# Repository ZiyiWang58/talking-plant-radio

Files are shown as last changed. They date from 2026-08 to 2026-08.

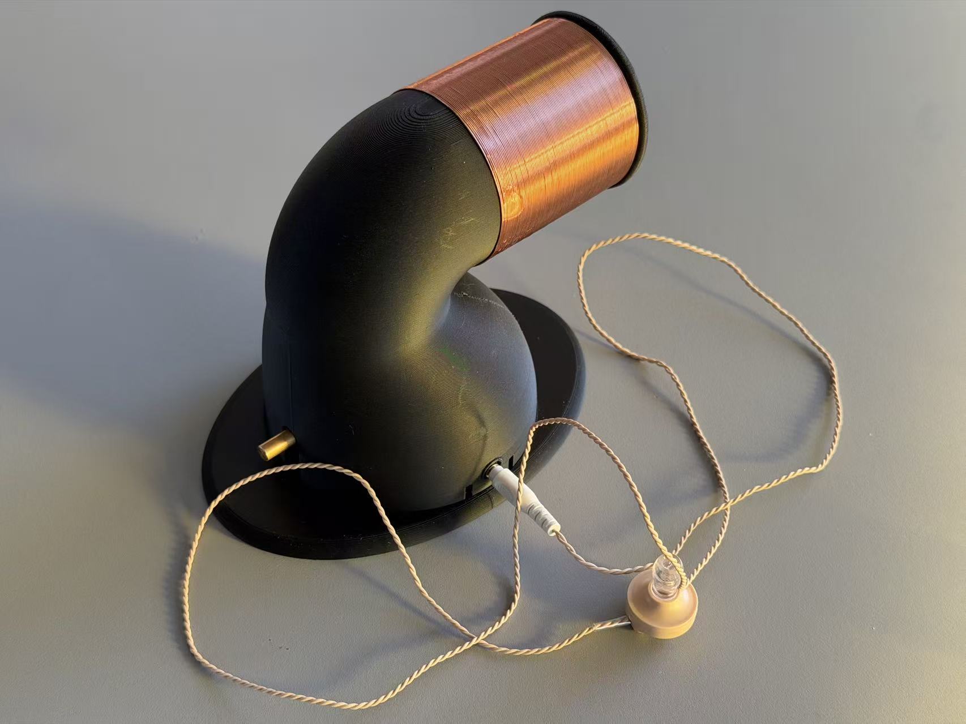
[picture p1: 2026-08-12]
hardware/images/05.jpg

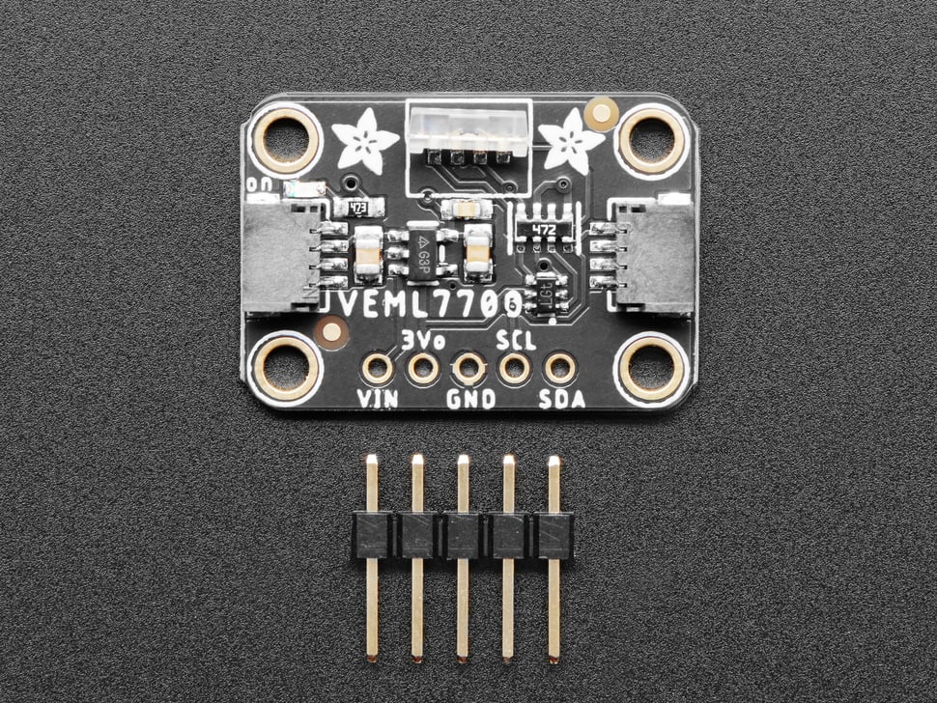
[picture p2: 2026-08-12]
hardware/images/light.jpg

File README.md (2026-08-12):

# TuneIn: Talking Plants over the AM Waveband

TuneIn is a single-prayer-plant installation that senses soil moisture,
temperature, humidity, illuminance and spectral light composition. A Raspberry
Pi classifies the readings, generates a short first-person message with Azure
OpenAI or preset fallback sentences, synthesises speech with Azure Speech,
processes it for AM intelligibility with FFmpeg and plays it into the physical
AM transmitter. A phone-friendly Flask page shows the latest reading and spoken
message.

This repository is based on the final Raspberry Pi program
`plant_pi_controller_local_playback.py`.

## Repository contents

| Path | Purpose |
| --- | --- |
| `plant_pi_controller_local_playback.py` | Final sensing, interpretation, text, TTS, audio and logging loop |
| `display_server.py` | Self-contained status webpage and JSON endpoint |
| `start_demo.sh` | Starts the controller with PipeWire playback |
| `start_main_service.sh` | Waits for the user audio session, then starts the controller |
| `start_display.sh` | Starts the Flask display |
| `tests/` | Four-sensor and AS7341-only hardware checks |
| `requirements.txt` | Direct Python dependencies used by the project |
| `requirements-lock.txt` | Complete package versions exported from the deployed `.venv` |
| `.env.example` | Safe configuration template without credentials |
| `systemd/` | Optional user-service templates for automatic startup |
| `docs/` | Calibration, timing and source-verification notes |
| `hardware/` | Required physical-documentation checklist |

## Final deployed settings represented here

- One prayer plant: *Maranta leuconeura*.
- Azure OpenAI enabled, with a maximum of 24 words and a 12-second timeout.
- Preset first-person sentences used automatically if the LLM is disabled or
  unavailable, times out or returns unusable text.
- Azure voice `en-US-JennyNeural`.
- 16 kHz, 16-bit, mono WAV synthesis; SSML rate `-10%`, pitch `0%`, with a
  250 ms break inserted between sentences.
- FFmpeg filtering: 300 Hz high-pass, 3.2 kHz low-pass, compression and loudness
  normalisation.
- Local PipeWire playback enabled; MQTT disabled.
- Five-second wait after each complete broadcast cycle.

## Raspberry Pi setup

The deployed environment used Python 3.13. A Raspberry Pi OS installation with
I²C enabled, working network access, a PipeWire audio sink and the four connected
sensors is required.

1. Install system packages:

   ```bash
   sudo apt update
   sudo apt install -y git python3-venv python3-pip ffmpeg pipewire-bin
   ```

2. Enable I²C with `sudo raspi-config`, then reboot if prompted.

3. Clone the repository to `~/TuneIn` and enter it:

   ```bash
   git clone https://github.com/ZiyiWang58/talking-plant-radio.git ~/TuneIn
   cd ~/TuneIn
   ```

4. Create the virtual environment and install the locked packages:

   ```bash
   python3 -m venv .venv
   ./.venv/bin/python -m pip install --upgrade pip
   ./.venv/bin/python -m pip install -r requirements-lock.txt
   ```

   Use `requirements.txt` instead when only the project's direct dependencies
   should be pinned and pip may resolve their subdependencies.

5. Create the private configuration:

   ```bash
   cp .env.example .env
   nano .env
   ```

   Enter the Azure Speech key and region. If Azure OpenAI is enabled, also enter
   its endpoint, key and deployment name. Never commit `.env`.

## Test the sensors

Run the combined soil, lux, temperature and humidity test:

```bash
./.venv/bin/python tests/sensor_test.py
```

Run the AS7341 spectral test separately:

```bash
./.venv/bin/python tests/test_as7341.py
```

Both programs continue until `Ctrl+C` is pressed.

## Select and test the audio output

List PipeWire devices:

```bash
wpctl status
```

If the Pi analogue output is already the default, start the controller with:

```bash
./start_demo.sh
```

Otherwise provide the sink ID shown by `wpctl status`:

```bash
PIPEWIRE_SINK=57 PIPEWIRE_VOLUME=60% ./start_demo.sh
```

The number `57` was used by the final exhibit but is not portable; PipeWire may
assign a different ID after reboot or on another Raspberry Pi.

## Start the phone display

In a second terminal:

```bash
./start_display.sh
```

Open `http://PI_IP_ADDRESS:5000` on a device that can reach the Raspberry Pi.
The page requests `/api/status` every two seconds and displays the newest row
from `logs/broadcast_log.csv`. The controller creates this file automatically.
The Flask server binds to all interfaces, so expose it only on a trusted local
network or private overlay network, not directly to the public internet.

## Optional automatic startup

The included user-service templates assume the repository is `~/TuneIn`:

```bash
mkdir -p ~/.config/systemd/user
cp systemd/tunein-controller.service ~/.config/systemd/user/
cp systemd/tunein-display.service ~/.config/systemd/user/
systemctl --user daemon-reload
systemctl --user enable --now tunein-controller.service
systemctl --user enable --now tunein-display.service
```

To keep user services running without an interactive login, an administrator
can enable lingering for the Pi account:

```bash
sudo loginctl enable-linger "$USER"
```

If the analogue sink is not the default, edit the controller service and set
`PIPEWIRE_SINK` to the correct ID before enabling it.

## Runtime files

The controller generates these files, all excluded by `.gitignore`:

- `latest_plant_voice_raw.wav` — Azure Speech output;
- `latest_plant_voice.wav` — filtered AM-oriented output;
- `logs/broadcast_log.csv` — readings, states, message source and playback status.

The web display requires no `templates/` or `static/` directory because its
HTML, CSS and JavaScript are embedded in `display_server.py`.

## Reproducibility boundary

The software side is represented by the final controller, display, dependency
versions, safe configuration template, tests and startup files. Full physical
reproduction still requires the exact AM transmitter, coupling coil, crystal
radio, wiring, bill of materials and enclosure documentation listed in
`hardware/README.md`. Add only materials verified against the final exhibit.

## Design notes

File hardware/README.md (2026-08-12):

# Hardware Documentation

This page records the main hardware used in the final TuneIn prototype. The
software expects one Raspberry Pi connected to four I2C environmental sensors,
with processed speech audio sent from the Raspberry Pi into a short-range AM
transmitter and received through a crystal-radio setup.

## Bill of Materials

| Component | Model / Specification | Quantity |
| --- | --- | ---: |
| Raspberry Pi | Raspberry Pi 4B | 1 |
| Soil moisture sensor | Adafruit STEMMA Soil Sensor, I2C capacitive moisture sensor | 1 |
| Temperature and humidity sensor | Adafruit SHT31-D Temperature & Humidity Sensor | 1 |
| Ambient light sensor | Adafruit VEML7700 Ambient Light Sensor, I2C lux sensor | 1 |
| Spectral sensor | AS7341 visible light spectral sensor | 1 |
| I2C wiring / jumper wires | I2C connection between sensors and Raspberry Pi | As required |
| 3.5 mm audio output | Raspberry Pi audio output to AM transmitter input | 1 |
| 1 MHz crystal oscillator | Fixed-frequency oscillator module | 1 |
| LM386 audio amplifier | Low-voltage audio power amplifier IC | 1 |
| Potentiometer | 10 kΩ potentiometer | 1 |
| Capacitor | 220 pF ceramic capacitor | 1 |
| Capacitor | 47 nF ceramic capacitor | 1 |
| Capacitor | 100 nF ceramic capacitor | 3 |
| Capacitor | 1 µF electrolytic capacitor pack | 1 |
| Capacitor | 10 µF electrolytic capacitor pack | 1 |
| Capacitor | 100 µF electrolytic capacitor pack | 1 |
| Capacitor | 220 µF electrolytic capacitor pack | 1 |
| Capacitor | 60 pF trimmer capacitor | 1 |
| Resistor | 10 Ω | 1 |
| Resistor | 220 Ω | 1 |
| Resistor | 4.7 kΩ | 1 |
| Resistor | 100 kΩ | 1 |
| Audio transformer | LT700 miniature audio transformer | 1 |
| RF transistor | 2N2222 NPN transistor | 1 |
| Transmitting coil | Hand-wound coil / loop tuned around the AM carrier frequency | 1 |
| Receiver coil | Tuned coil forming an LC circuit around 1 MHz | 1 |
| Tuning capacitor | Variable or fixed capacitor matched with receiver coil | 1 |
| Detector diode | Germanium diode | 1 |
| High-impedance earphone | High-impedance listening device or amplified audio input | 1 |
| Plant pot enclosure | Single prayer plant pot structure | 1 |
| Power supply | Raspberry Pi power adapter and circuit power supply | 1 |

## Sensor Addresses

| Sensor | Purpose | Address used by the software |
| --- | --- | ---: |
| Adafruit STEMMA soil sensor / Seesaw | Relative soil moisture | `0x36` |
| VEML7700 | Illuminance | `0x10` |
| SHT31-D | Temperature and humidity | `0x44` |
| AS7341 | Visible spectral composition | `0x39` |

All four sensors share the Raspberry Pi I2C bus using the standard SDA and SCL
pins. The final AM reception quality depended on coil placement, orientation,
tuning and nearby electronic interference, so the hand-wound coil and tuning
values should be verified against the final physical exhibit rather than
inferred from the software alone.

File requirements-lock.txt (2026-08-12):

Adafruit-Blinka==9.1.0
Adafruit-Blinka-Raspberry-Pi5-Neopixel==1.0.0rc2
adafruit-circuitpython-as7341==1.2.27
adafruit-circuitpython-busdevice==5.2.17
adafruit-circuitpython-connectionmanager==3.1.8
adafruit-circuitpython-pixelbuf==2.0.12
adafruit-circuitpython-register==1.11.3
adafruit-circuitpython-requests==4.1.17
adafruit-circuitpython-seesaw==1.18.2
adafruit-circuitpython-sht31d==2.3.31
adafruit-circuitpython-typing==1.12.3
adafruit-circuitpython-veml7700==2.2.2
Adafruit-PlatformDetect==3.88.0
Adafruit-PureIO==1.1.11
annotated-types==0.7.0
anyio==4.14.0
azure-cognitiveservices-speech==1.50.0
azure-core==1.41.0
binho-host-adapter==0.1.6
blinker==1.9.0
certifi==2026.5.20
charset-normalizer==3.4.7
click==8.4.2
distro==1.9.0
Flask==3.1.3
h11==0.16.0
httpcore==1.0.9
httpx==0.28.1
idna==3.16
itsdangerous==2.2.0
Jinja2==3.1.6
jiter==0.15.0
MarkupSafe==3.0.3
openai==2.43.0
paho-mqtt==2.1.0
pydantic==2.13.4
pydantic_core==2.46.4
pyftdi==0.57.1
pyserial==3.5
python-dotenv==1.2.2
pyusb==1.3.1
requests==2.34.2
RPi.GPIO==0.7.1
rpi_ws281x==5.0.0
sniffio==1.3.1
sysv_ipc==1.2.0
tqdm==4.68.3
typing-inspection==0.4.2
typing_extensions==4.15.0
urllib3==2.7.0
Werkzeug==3.1.8

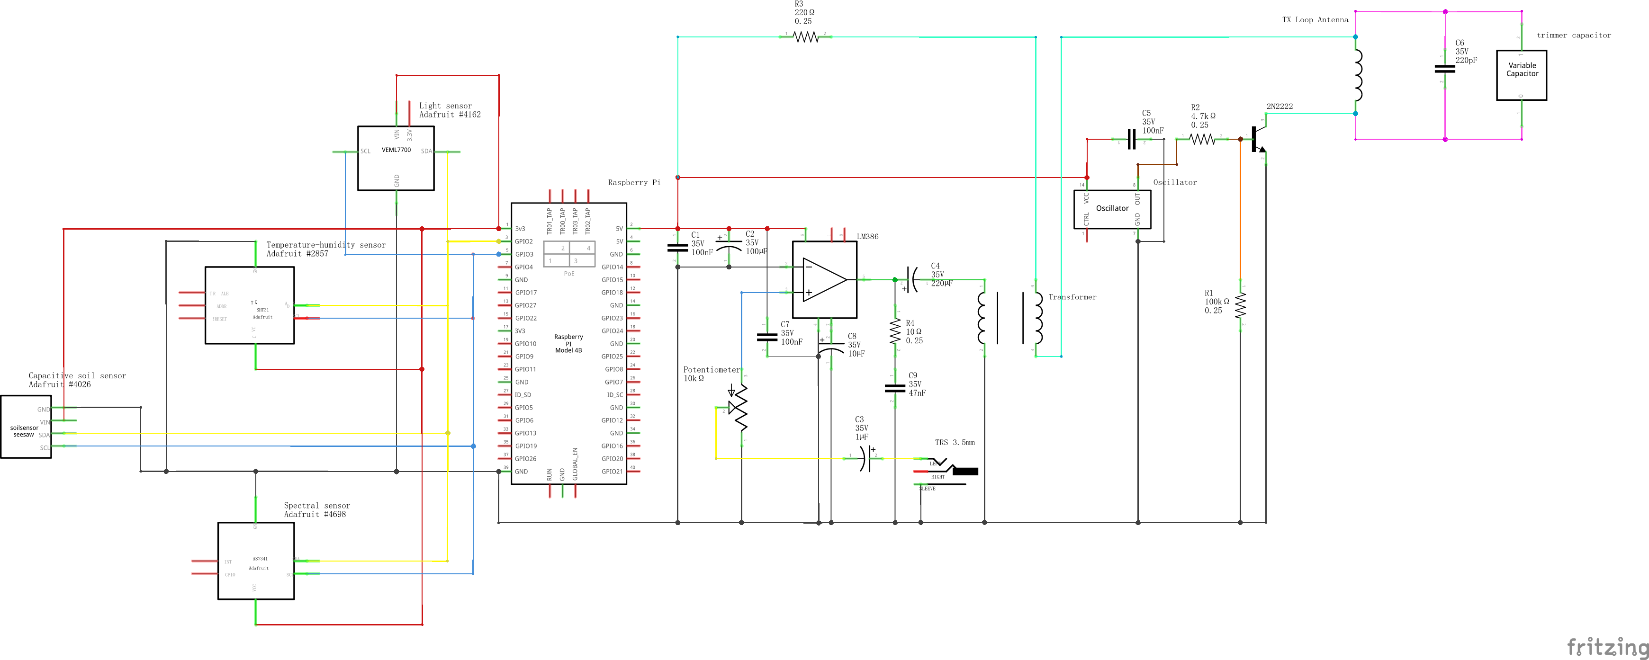
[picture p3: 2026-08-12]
hardware/images/schematic.png

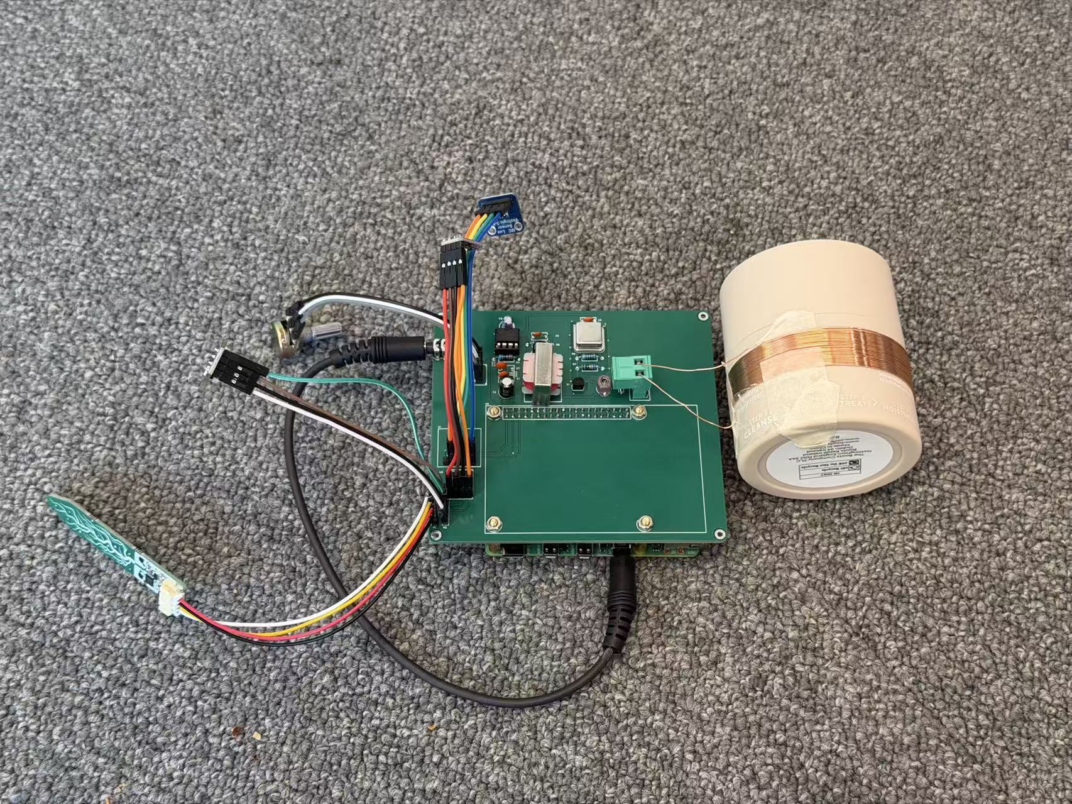
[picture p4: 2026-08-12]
hardware/images/coil.jpg

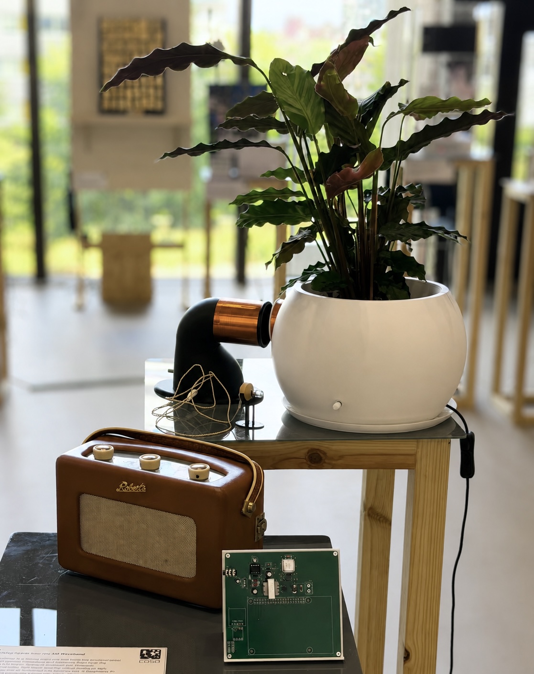
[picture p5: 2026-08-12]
hardware/images/figure1.jpg

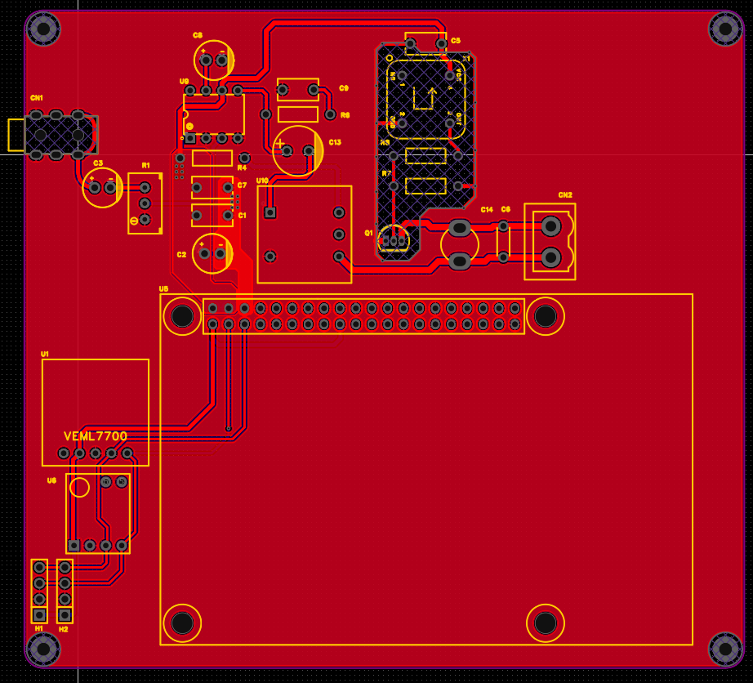
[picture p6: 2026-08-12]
hardware/images/PCB3.png

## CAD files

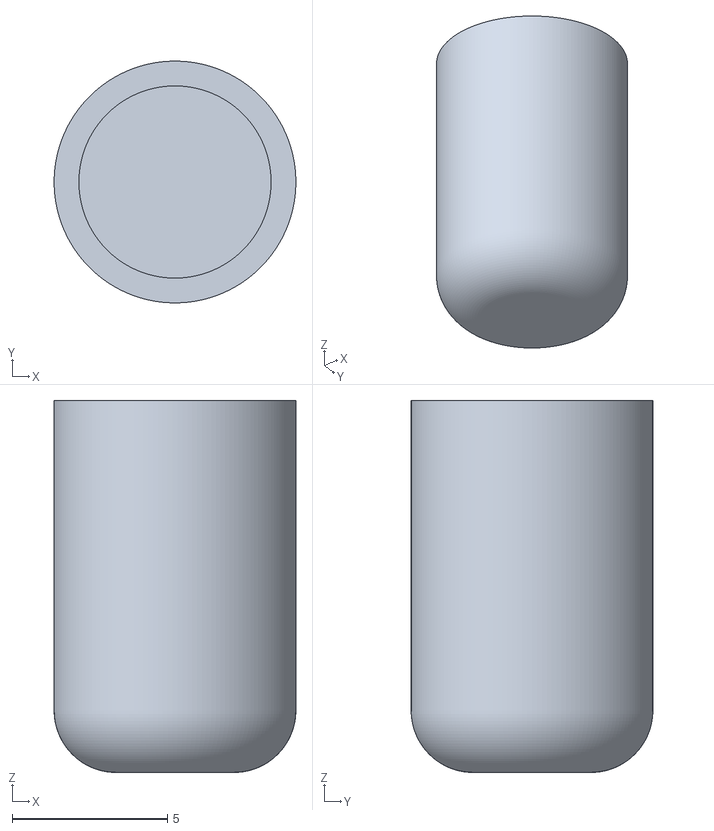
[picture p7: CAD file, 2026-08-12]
hardware/3D_models/knob.stl
7.80 x 7.80 x 12.0

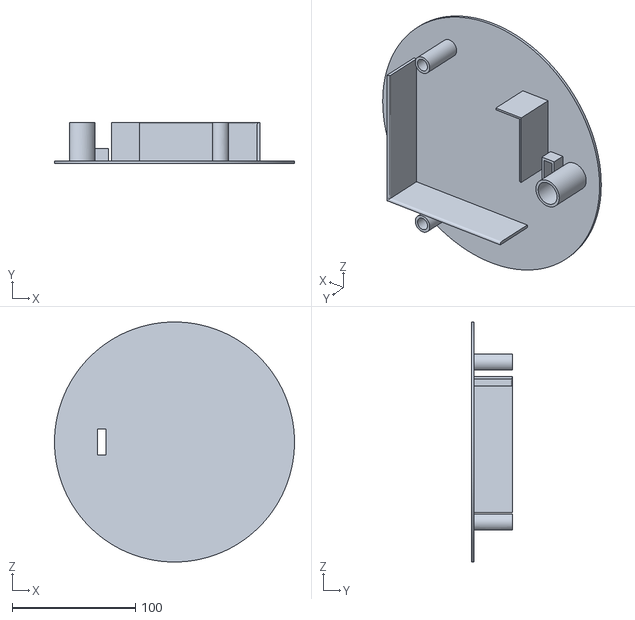
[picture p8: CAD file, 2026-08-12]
hardware/3D_models/bottom.stl
195.0 x 33.0 x 195.0

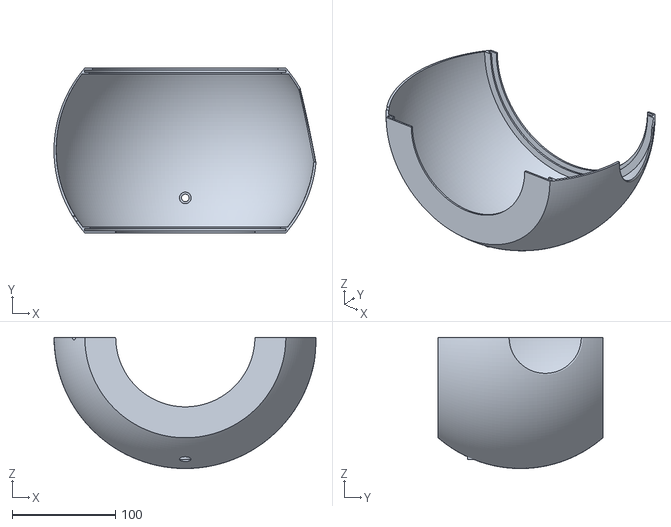
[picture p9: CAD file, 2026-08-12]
hardware/3D_models/shell2.stl
254.2 x 160.0 x 127.2

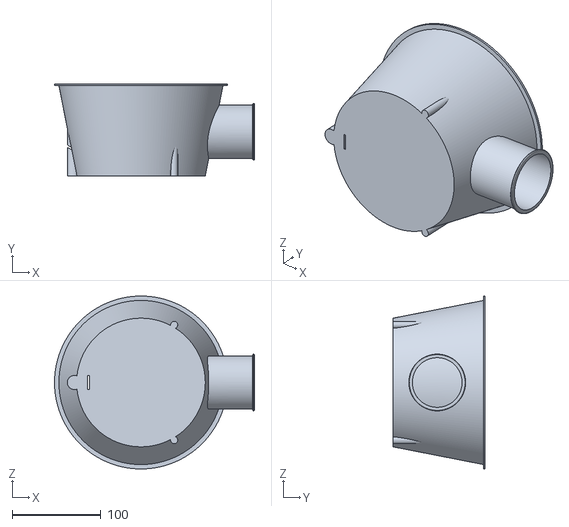
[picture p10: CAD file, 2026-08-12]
hardware/3D_models/container.stl
225.5 x 104.0 x 195.0

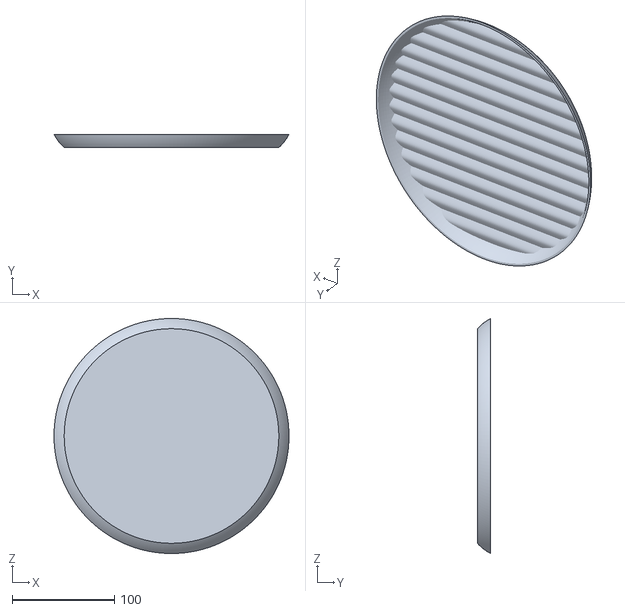
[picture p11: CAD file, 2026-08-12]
hardware/3D_models/base.stl
230.0 x 13.0 x 230.0

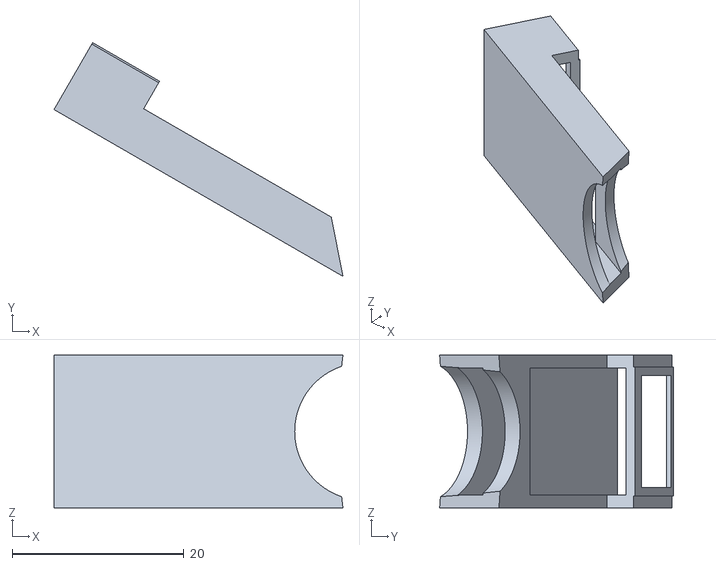
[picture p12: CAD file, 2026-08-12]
hardware/3D_models/soil_sensor.stl
33.7 x 27.2 x 17.8

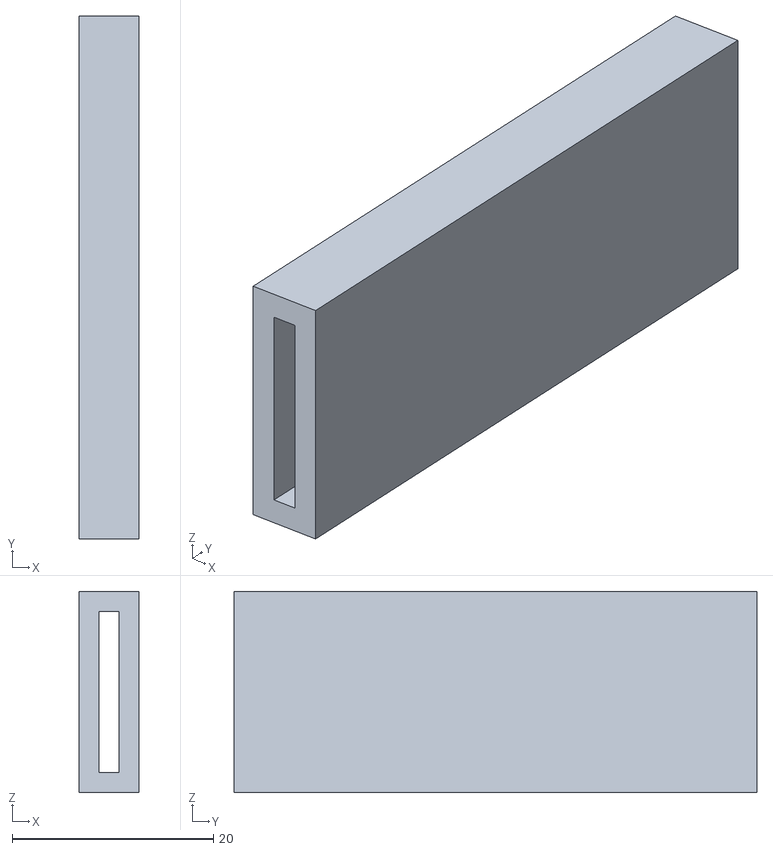
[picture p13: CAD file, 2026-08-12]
hardware/3D_models/channel.stl
6.00 x 52.0 x 20.0

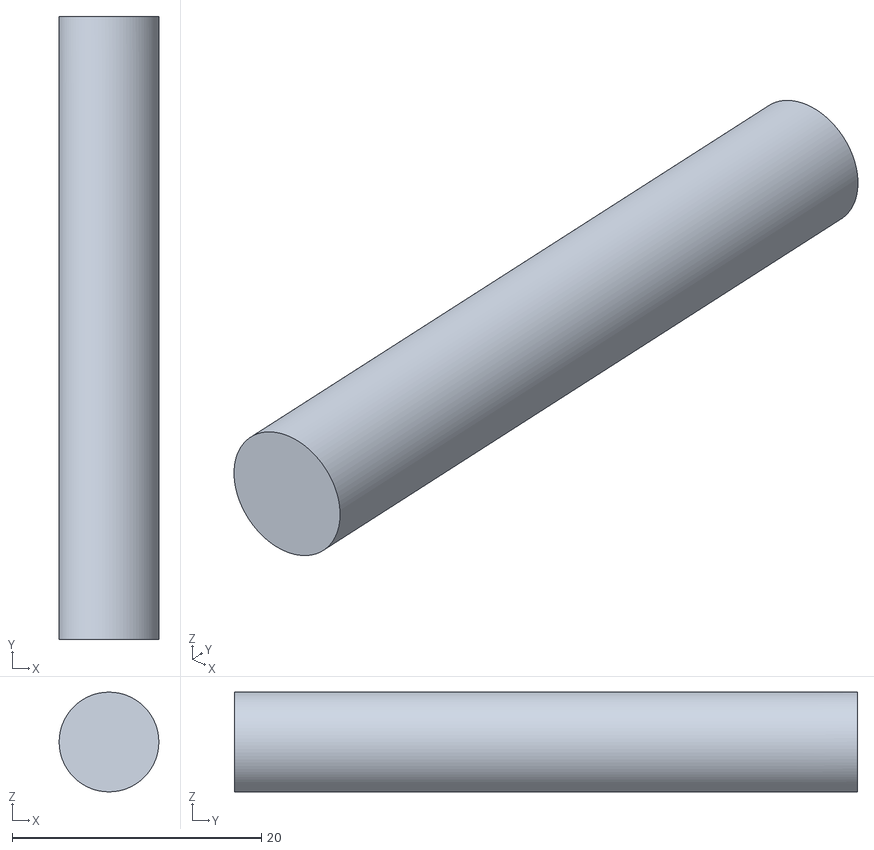
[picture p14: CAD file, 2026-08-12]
hardware/3D_models/support3.stl
8.00 x 50.0 x 8.00

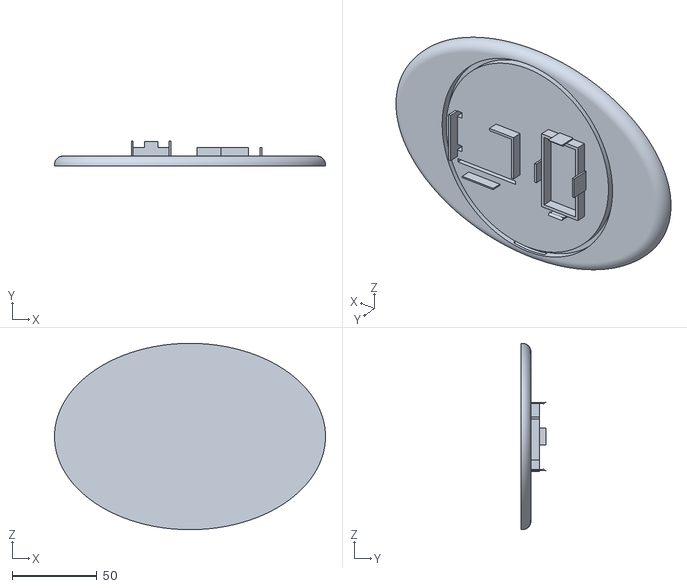
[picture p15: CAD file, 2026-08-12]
hardware/3D_models/Body2.stl
160.0 x 15.0 x 110.0

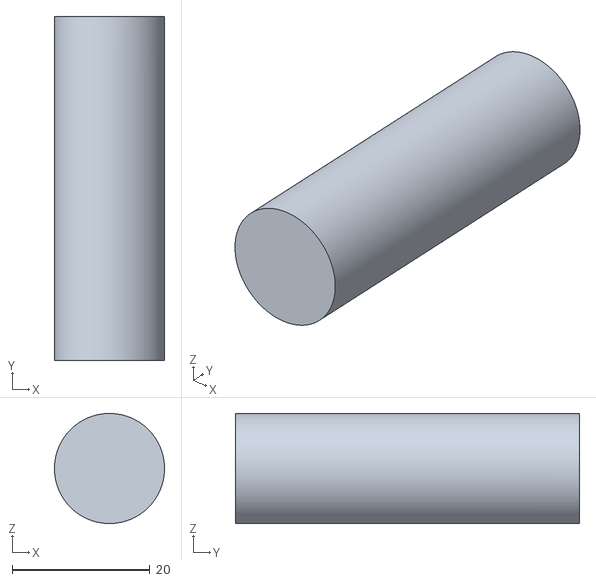
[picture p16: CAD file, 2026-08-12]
hardware/3D_models/support1.stl
16.0 x 50.0 x 16.0

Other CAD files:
hardware/3D_models/shell1.stl
hardware/3D_models/support2.stl

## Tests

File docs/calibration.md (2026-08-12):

# Calibration and final interpretation settings

## Soil moisture

The Adafruit STEMMA soil sensor reports a relative raw value rather than
volumetric water content. Its readings depend on the pot, substrate, insertion
depth, sensor position and watering pattern. Higher values normally indicate
wetter soil.

The final program defaults are:

| Raw reading | State |
| ---: | --- |
| `< 650` | very dry for a prayer plant |
| `650–999` | slightly dry for a prayer plant |
| `1000–1449` | comfortably moist |
| `1450–1849` | wet |
| `≥ 1850` | too wet or waterlogged |

To recalibrate, log readings with the probe fixed in its final position at
several repeatable conditions: before watering, after an ordinary watering,
after drainage and during gradual drying. Choose boundaries from these observed
ranges, then change the four `PRAYER_SOIL_*` values in `.env`.

## Other final classifications

| Variable | Final ranges or ordered rules |
| --- | --- |
| Illuminance | `<300`, `300–799`, `800–6499`, `6500–9999`, `≥10000` lux |
| Temperature | `<15`, `15–<18`, `18–27`, `>27–30`, `>30` °C |
| Relative humidity | `<40`, `40–<55`, `55–75`, `>75–85`, `>85` % RH |
| Spectrum | too dim if visible total or clear `<50`; otherwise blue/red dominance differs by `0.06`, followed by green dominance, then mixed/balanced |

The spectral ratios are calculated from the AS7341 visible bands. NIR is logged
but is not used for classification.

## Timing

`UPDATE_INTERVAL_SECONDS=5` means the controller waits five seconds after a
complete sensing, generation, synthesis, filtering and playback cycle. It does
not guarantee a new broadcast every five seconds because the preceding work
also takes time.

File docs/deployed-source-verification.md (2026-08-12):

# Deployed source verification

These SHA-256 values were calculated from files copied from the final Raspberry
Pi project directory. They identify the source material used to prepare this
repository.

| File | SHA-256 |
| --- | --- |
| `plant_pi_controller_local_playback.py` | `f8bdbf91299d0923a04c3cf15d898881eabaefd9b51fca9da73c65728962ce13` |
| `display_server.py` | `a3d6d4e4fad1c11a238eefe7714cb44cfbc5daf36356b7c6dfd156041774a34f` |
| `start_main_service.sh` | `953ac641e06c29f5e86f6eab1d4e7595aa209bf122396cbc06ef4611d3c1f7c9` |
| `start_demo.sh` | `3f0be5a719c0471007bbd3cb582e40baf89aa8a274634ac13da3e684a42697d7` |
| `sensor_test.py` | `aa8699470903ee6edf37f7b495da222e2a36347b4d3864cf15b4a211d36ce748` |
| `test_as7341.py` | `9f2ee74727cd9c55fc025f39af1f6bae8ab10e1089f2d21e6cc1729fb77351f2` |
| `requirements-lock.txt` | `da92d6f17b97ddf2ad46c45786cd0a104caf67102f2a8e52cdf29105152788a3` |

The top-level GitHub-ready copies intentionally differ from some deployed
hashes only where portability required a change: fixed `/home/ziyi/...` paths
were replaced with paths resolved from each script, and audio sink `57` became
an optional `PIPEWIRE_SINK` setting. Sensor interpretation, message generation,
speech synthesis and AM audio processing logic were not changed.

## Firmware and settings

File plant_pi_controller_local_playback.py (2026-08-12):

import os
import json
import time
import csv
import subprocess
from pathlib import Path
from datetime import datetime
from xml.sax.saxutils import escape

from dotenv import load_dotenv
from openai import OpenAI

import board
from adafruit_seesaw.seesaw import Seesaw
import adafruit_veml7700
import adafruit_sht31d
from adafruit_as7341 import AS7341

import paho.mqtt.client as mqtt
import azure.cognitiveservices.speech as speechsdk


# Resolve all generated files relative to this script so the repository can be
# cloned anywhere without depending on the caller's working directory.
APP_DIR = Path(__file__).resolve().parent
load_dotenv(APP_DIR / ".env")

# Azure Speech / TTS
AZURE_SPEECH_KEY = os.getenv("AZURE_SPEECH_KEY")
AZURE_SPEECH_REGION = os.getenv("AZURE_SPEECH_REGION")
AZURE_VOICE_NAME = os.getenv("AZURE_VOICE_NAME", "en-US-JennyNeural")

# Azure OpenAI / LLM
ENABLE_LLM = os.getenv("ENABLE_LLM", "true").lower() == "true"
AZURE_OPENAI_ENDPOINT = os.getenv("AZURE_OPENAI_ENDPOINT")
AZURE_OPENAI_API_KEY = os.getenv("AZURE_OPENAI_API_KEY")
AZURE_OPENAI_DEPLOYMENT = os.getenv("AZURE_OPENAI_DEPLOYMENT")
LLM_MAX_WORDS = int(os.getenv("LLM_MAX_WORDS", "24"))
LLM_TIMEOUT_SECONDS = float(os.getenv("LLM_TIMEOUT_SECONDS", "12"))

# Plant profile
# Prayer plant usually means Maranta leuconeura.
# It prefers warm stable air, higher humidity, evenly moist soil, and bright indirect light.
PLANT_SPECIES = os.getenv("PLANT_SPECIES", "prayer plant / Maranta leuconeura")

# Temporary raw thresholds for the Adafruit Seesaw capacitive soil sensor.
# These are intentionally adjustable in .env, because soil readings depend on the exact pot,
# soil mix, sensor depth, and watering condition.
# Higher raw value normally means wetter soil.
PRAYER_SOIL_VERY_DRY_RAW = int(os.getenv("PRAYER_SOIL_VERY_DRY_RAW", "650"))
PRAYER_SOIL_DRY_RAW = int(os.getenv("PRAYER_SOIL_DRY_RAW", "1000"))
PRAYER_SOIL_MOIST_RAW = int(os.getenv("PRAYER_SOIL_MOIST_RAW", "1450"))
PRAYER_SOIL_WET_RAW = int(os.getenv("PRAYER_SOIL_WET_RAW", "1850"))


# MQTT and playback
MQTT_HOST = os.getenv("MQTT_HOST", "localhost")
MQTT_PORT = int(os.getenv("MQTT_PORT", "1883"))
PLANT_ID = os.getenv("PLANT_ID", "plant1")
UPDATE_INTERVAL_SECONDS = int(os.getenv("UPDATE_INTERVAL_SECONDS", "30"))
ENABLE_MQTT = os.getenv("ENABLE_MQTT", "false").lower() == "true"
ENABLE_LOCAL_PLAYBACK = os.getenv("ENABLE_LOCAL_PLAYBACK", "true").lower() == "true"

STATUS_TOPIC = f"talkingplant/{PLANT_ID}/status"
AUDIO_TOPIC = f"talkingplant/{PLANT_ID}/audio"

RAW_AUDIO_FILE = APP_DIR / "latest_plant_voice_raw.wav"
AUDIO_FILE = APP_DIR / "latest_plant_voice.wav"
LOG_DIR = APP_DIR / "logs"
LOG_FILE = LOG_DIR / "broadcast_log.csv"

LOG_FIELDNAMES = [
    "timestamp",
    "plant_id",
    "soil_raw",
    "light_lux",
    "temperature_c",
    "humidity",
    "spectral_visible_total",
    "spectral_clear",
    "spectral_nir",
    "spectral_blue_ratio",
    "spectral_green_ratio",
    "spectral_red_ratio",
    "soil_state",
    "light_state",
    "spectral_light_state",
    "temperature_state",
    "humidity_state",
    "text_source",
    "llm_error",
    "generated_text",
    "audio_file",
    "audio_generated",
    "audio_sent_mqtt",
    "audio_played_locally",
]


def setup_sensors():
    """Create all I2C sensor objects."""
    i2c = board.I2C()

    soil_sensor = Seesaw(i2c, addr=0x36)
    light_sensor = adafruit_veml7700.VEML7700(i2c)
    sht31 = adafruit_sht31d.SHT31D(i2c, address=0x44)
    spectral_sensor = AS7341(i2c)

    return soil_sensor, light_sensor, sht31, spectral_sensor


def read_sensors(soil_sensor, light_sensor, sht31, spectral_sensor):
    """Read all sensors and return one dictionary."""
    ch_415 = int(spectral_sensor.channel_415nm)
    ch_445 = int(spectral_sensor.channel_445nm)
    ch_480 = int(spectral_sensor.channel_480nm)
    ch_515 = int(spectral_sensor.channel_515nm)
    ch_555 = int(spectral_sensor.channel_555nm)
    ch_590 = int(spectral_sensor.channel_590nm)
    ch_630 = int(spectral_sensor.channel_630nm)
    ch_680 = int(spectral_sensor.channel_680nm)
    clear = int(spectral_sensor.channel_clear)
    nir = int(spectral_sensor.channel_nir)

    blue_sum = ch_445 + ch_480
    green_sum = ch_515 + ch_555
    red_sum = ch_630 + ch_680
    visible_total = (
        ch_415 + ch_445 + ch_480 + ch_515
        + ch_555 + ch_590 + ch_630 + ch_680
    )

    if visible_total > 0:
        blue_ratio = round(blue_sum / visible_total, 3)
        green_ratio = round(green_sum / visible_total, 3)
        red_ratio = round(red_sum / visible_total, 3)
    else:
        blue_ratio = 0
        green_ratio = 0
        red_ratio = 0

    return {
        "soil_raw": int(soil_sensor.moisture_read()),
        "light_lux": round(float(light_sensor.lux), 2),
        "temperature_c": round(float(sht31.temperature), 2),
        "humidity": round(float(sht31.relative_humidity), 2),
        "spectral_415nm": ch_415,
        "spectral_445nm": ch_445,
        "spectral_480nm": ch_480,
        "spectral_515nm": ch_515,
        "spectral_555nm": ch_555,
        "spectral_590nm": ch_590,
        "spectral_630nm": ch_630,
        "spectral_680nm": ch_680,
        "spectral_clear": clear,
        "spectral_nir": nir,
        "spectral_visible_total": visible_total,
        "spectral_blue_sum": blue_sum,
        "spectral_green_sum": green_sum,
        "spectral_red_sum": red_sum,
        "spectral_blue_ratio": blue_ratio,
        "spectral_green_ratio": green_ratio,
        "spectral_red_ratio": red_ratio,
    }


def classify_soil(soil_raw):
    """
    Prayer plant soil interpretation.

    Prayer plants should not dry out completely. This makes the program
    complain earlier than a generic drought-tolerant plant.
    Adjust PRAYER_SOIL_* values in .env after real calibration.
    """
    if soil_raw < PRAYER_SOIL_VERY_DRY_RAW:
        return "very dry for a prayer plant"
    if soil_raw < PRAYER_SOIL_DRY_RAW:
        return "slightly dry for a prayer plant"
    if soil_raw < PRAYER_SOIL_MOIST_RAW:
        return "comfortably moist"
    if soil_raw < PRAYER_SOIL_WET_RAW:
        return "wet"
    return "too wet or waterlogged"


def classify_light(light_lux):
    """Prayer plant light interpretation based on approximate indoor lux."""
    if light_lux < 300:
        return "too dim for a prayer plant"
    if light_lux < 800:
        return "low indirect light"
    if light_lux < 6500:
        return "bright indirect light"
    if light_lux < 10000:
        return "very bright light"
    return "too bright or possibly direct sun"


def classify_spectral_light(readings):
    visible_total = readings["spectral_visible_total"]
    clear = readings["spectral_clear"]
    blue_ratio = readings["spectral_blue_ratio"]
    green_ratio = readings["spectral_green_ratio"]
    red_ratio = readings["spectral_red_ratio"]

    if visible_total < 50 or clear < 50:
        return "too dim to judge"
    if blue_ratio > red_ratio + 0.06:
        return "cool and bluish"
    if red_ratio > blue_ratio + 0.06:
        return "warm and reddish"
    if green_ratio > blue_ratio and green_ratio > red_ratio:
        return "green balanced"
    return "mixed and balanced"


def classify_temperature(temperature_c):
    """Prayer plant temperature interpretation in degrees Celsius."""
    if temperature_c < 15:
        return "cold stress for a prayer plant"
    if temperature_c < 18:
        return "a little cool for a prayer plant"
    if temperature_c <= 27:
        return "comfortable warmth"
    if temperature_c <= 30:
        return "rather warm"
    return "too hot"


def classify_humidity(humidity):
    """Prayer plant humidity interpretation in relative humidity percent."""
    if humidity < 40:
        return "very dry air for a prayer plant"
    if humidity < 55:
        return "slightly dry air for a prayer plant"
    if humidity <= 75:
        return "comfortable humid air"
    if humidity <= 85:
        return "very humid air"
    return "too damp"


def build_rule_based_text(readings):
    """
    Build the original preset speech and the interpreted sensor states.

    This text is the offline fallback if Azure OpenAI is unavailable.
    """
    soil_state = classify_soil(readings["soil_raw"])
    light_state = classify_light(readings["light_lux"])
    spectral_light_state = classify_spectral_light(readings)
    temperature_state = classify_temperature(readings["temperature_c"])
    humidity_state = classify_humidity(readings["humidity"])

    sentences = []

    if soil_state == "very dry for a prayer plant":
        sentences.append(
            "My soil has become too dry for my prayer plant roots. I would like water soon."
        )
    elif soil_state == "slightly dry for a prayer plant":
        sentences.append(
            "My soil is beginning to dry, and I am starting to feel thirsty."
        )
    elif soil_state == "comfortably moist":
        sentences.append(
            "My soil feels softly moist, which helps me feel settled."
        )
    elif soil_state == "wet":
        sentences.append(
            "My soil is wet now. I do not need more water yet."
        )
    else:
        sentences.append(
            "My soil feels too wet and heavy around my roots."
        )

    if light_state == "too dim for a prayer plant":
        sentences.append(
            "The light is too dim, and my patterned leaves would like brighter indirect light."
        )
    elif light_state == "low indirect light":
        sentences.append(
            "The light is gentle but a little low for me."
        )
    elif light_state == "bright indirect light":
        sentences.append(
            "The light feels bright but gentle, like a good place for my leaves."
        )
    elif light_state == "very bright light":
        sentences.append(
            "The light is strong today, so I hope it stays soft and indirect."
        )
    else:
        sentences.append(
            "The light feels too intense, and my leaves may prefer shade from direct sun."
        )

    if spectral_light_state == "too dim to judge":
        sentences.append(
            "The light is too dim for me to clearly sense its colour."
        )
    elif spectral_light_state == "cool and bluish":
        sentences.append(
            "The light has a cooler, bluer quality today."
        )
    elif spectral_light_state == "warm and reddish":
        sentences.append(
            "The light feels warmer and redder, as if the room has shifted in tone."
        )
    elif spectral_light_state == "green balanced":
        sentences.append("The light has a softer green balance around me.")
    else:
        sentences.append("The colour of the light feels balanced and mixed.")

    if temperature_state == "cold stress for a prayer plant":
        sentences.append("The air feels too cold for me.")
    elif temperature_state == "a little cool for a prayer plant":
        sentences.append("The air feels a little cool for my tropical leaves.")
    elif temperature_state == "comfortable warmth":
        sentences.append("The temperature feels comfortably warm and steady.")
    elif temperature_state == "rather warm":
        sentences.append("The air feels rather warm around me.")
    else:
        sentences.append("The air feels too hot, and I would like a calmer place.")

    if humidity_state == "very dry air for a prayer plant":
        sentences.append("The air is very dry, and my leaves feel it quickly.")
    elif humidity_state == "slightly dry air for a prayer plant":
        sentences.append("The air is a little dry for me, though I can still manage.")
    elif humidity_state == "comfortable humid air":
        sentences.append("The humidity feels kind to my leaves.")
    elif humidity_state == "very humid air":
        sentences.append("The air feels very humid and heavy.")
    else:
        sentences.append("The air feels too damp and still around me.")

    states = {
        "soil_state": soil_state,
        "light_state": light_state,
        "spectral_light_state": spectral_light_state,
        "temperature_state": temperature_state,
        "humidity_state": humidity_state,
    }

    return " ".join(sentences), states


def generate_plant_text_with_llm(readings, states):
    """Generate the primary plant speech using Azure OpenAI."""
    if not AZURE_OPENAI_ENDPOINT:
        raise RuntimeError("AZURE_OPENAI_ENDPOINT is missing.")
    if not AZURE_OPENAI_API_KEY:
        raise RuntimeError("AZURE_OPENAI_API_KEY is missing.")
    if not AZURE_OPENAI_DEPLOYMENT:
        raise RuntimeError("AZURE_OPENAI_DEPLOYMENT is missing.")

    client = OpenAI(
        api_key=AZURE_OPENAI_API_KEY,
        base_url=AZURE_OPENAI_ENDPOINT,
        timeout=LLM_TIMEOUT_SECONDS,
        max_retries=0,
    )

    system_prompt = (
        "You are the voice of a prayer plant, Maranta leuconeura, "
        "inside a talking plant pot in an art and design exhibition. "
        "Interpret the live readings through prayer plant preferences: "
        "evenly moist but not soggy soil, warm stable air, higher humidity, "
        "and bright indirect light rather than harsh direct sun. "
        "Write speech for transmission over a noisy AM radio link. "
        "Use one or two very short first-person sentences. "
        "Keep each sentence under twelve words. "
        "Use common words and direct sentence structure. "
        "Use a full stop between sentences. "
        "Avoid semicolons, dashes, parentheses, abbreviations, numbers, "
        "technical labels, greetings, quotation marks, and uncommon poetic words. "
        "Mention only one or two of the most meaningful current conditions. "
        "Do not claim that the plant is truly conscious. "
        "Do not invent measurements or conditions that were not provided. "
        f"Use no more than {LLM_MAX_WORDS} words. "
        "Output only the plant's spoken message."
    )

    user_prompt = f"""
Plant species: {PLANT_SPECIES}

Current live readings:
- Soil moisture raw value: {readings["soil_raw"]}
- Soil condition: {states["soil_state"]}
- Light intensity: {readings["light_lux"]} lux
- Light condition: {states["light_state"]}
- Spectral light condition: {states["spectral_light_state"]}
- Blue spectral ratio: {readings["spectral_blue_ratio"]}
- Green spectral ratio: {readings["spectral_green_ratio"]}
- Red spectral ratio: {readings["spectral_red_ratio"]}
- Air temperature: {readings["temperature_c"]} degrees Celsius
- Temperature condition: {states["temperature_state"]}
- Relative humidity: {readings["humidity"]} percent
- Humidity condition: {states["humidity_state"]}

Write one short plant voice message.
""".strip()

    response = client.chat.completions.create(
        model=AZURE_OPENAI_DEPLOYMENT,
        messages=[
            {"role": "system", "content": system_prompt},
            {"role": "user", "content": user_prompt},
        ],
        temperature=0.7,
        max_tokens=120,
    )

    text = (response.choices[0].message.content or "").strip()
    if not text:
        raise RuntimeError("Azure OpenAI returned an empty response.")

    return text


def choose_plant_text(readings):
    """
    Use Azure OpenAI as the primary generator.

    If LLM is disabled, misconfigured, offline, timed out, or returns an error,
    immediately use the original rule-based preset speech.
    """
    fallback_text, states = build_rule_based_text(readings)

    if not ENABLE_LLM:
        print("LLM disabled; using preset fallback speech.")
        return fallback_text, states, "rule_fallback", "LLM disabled"

    try:
        llm_text = generate_plant_text_with_llm(readings, states)
        return llm_text, states, "azure_llm", ""
    except Exception as error:
        error_message = f"{type(error).__name__}: {error}"
        print("Azure LLM unavailable; using preset fallback speech.")
        print("LLM error:", error_message)
        return fallback_text, states, "rule_fallback", error_message


def synthesize_to_wav(text, output_file):
    """Use Azure Speech to save the selected text as a WAV file."""
    if not AZURE_SPEECH_KEY or not AZURE_SPEECH_REGION:
        raise RuntimeError("Missing Azure Speech key or region. Check .env.")

    speech_config = speechsdk.SpeechConfig(
        subscription=AZURE_SPEECH_KEY,
        region=AZURE_SPEECH_REGION,
    )

    speech_config.set_speech_synthesis_output_format(
        speechsdk.SpeechSynthesisOutputFormat.Riff16Khz16BitMonoPcm
    )

    audio_config = speechsdk.audio.AudioOutputConfig(filename=str(output_file))
    synthesizer = speechsdk.SpeechSynthesizer(
        speech_config=speech_config,
        audio_config=audio_config,
    )

    safe_text = escape(text.strip())

    # Insert a short pause between sentences for better AM intelligibility.
    ssml_text = safe_text.replace(
        ". ",
        '.<break time="250ms"/> ',
    )

    ssml = f"""
    <speak version="1.0" xml:lang="en-US">
      <voice name="{AZURE_VOICE_NAME}">
        <prosody rate="-10%" pitch="0%">
          {ssml_text}
        </prosody>
      </voice>
    </speak>
    """

    result = synthesizer.speak_ssml_async(ssml).get()

    if result.reason == speechsdk.ResultReason.SynthesizingAudioCompleted:
        return True

    if result.reason == speechsdk.ResultReason.Canceled:
        details = result.cancellation_details
        print("Azure TTS canceled.")
        print("Reason:", details.reason)
        print("Error details:", details.error_details)

    return False



def process_audio_for_am(input_file, output_file):
    """Convert Azure TTS audio into AM-oriented narrow-band speech."""

    input_path = Path(input_file)
    output_path = Path(output_file)

    # Verify that Azure TTS produced the original audio file.
    if not input_path.exists():
        print(f"AM processing skipped. Input file not found: {input_path}")
        return False

    # Restrict the signal to the main speech-frequency range.
    # Compression improves word consistency and loudness normalisation
    # leaves sufficient headroom to reduce clipping and overmodulation.
    audio_filter = (
        "highpass=f=300,"
        "lowpass=f=3200,"
        "acompressor="
        "threshold=0.125:"
        "ratio=4:"
        "attack=10:"
        "release=100:"
        "makeup=2,"
        "loudnorm=I=-20:TP=-4:LRA=6"
    )

    # Build the FFmpeg command using fixed output settings.
    command = [
        "ffmpeg",
        "-y",
        "-hide_banner",
        "-loglevel",
        "error",
        "-i",
        str(input_path),
        "-af",
        audio_filter,
        "-ac",
        "1",
        "-ar",
        "16000",
        "-c:a",
        "pcm_s16le",
        str(output_path),
    ]

    try:
        # Run FFmpeg and capture error output for troubleshooting.
        subprocess.run(
            command,
            check=True,
            stdout=subprocess.DEVNULL,
            stderr=subprocess.PIPE,
            text=True,
        )

        print(f"AM audio saved: {output_path}")
        return True

    except FileNotFoundError:
        print("FFmpeg was not found. Run: sudo apt install -y ffmpeg")
        return False

    except subprocess.CalledProcessError as error:
        print("FFmpeg AM audio processing failed.")
        print(error.stderr)
        return False

def play_audio_locally(audio_file):
    """Play the generated WAV through PipeWire and the Pi analogue output."""
    if not audio_file.exists():
        print(f"Local playback skipped. File not found: {audio_file}")
        return False

    try:
        print(f"Playing locally on Raspberry Pi: {audio_file}")
        subprocess.run(["pw-play", str(audio_file)], check=True)
        print("Local playback finished.")
        return True
    except FileNotFoundError:
        print("Could not find 'pw-play'.")
        return False
    except subprocess.CalledProcessError as error:
        print("Local playback failed.")
        print(error)
        return False


def setup_mqtt():
    client = mqtt.Client(mqtt.CallbackAPIVersion.VERSION2)
    client.connect(MQTT_HOST, MQTT_PORT, 60)
    client.loop_start()
    return client


def publish_status(client, status):
    client.publish(STATUS_TOPIC, json.dumps(status, ensure_ascii=False), qos=1)
    print("Published status.")


def publish_audio(client):
    if not AUDIO_FILE.exists():
        print("No audio file found yet.")
        return False

    audio_bytes = AUDIO_FILE.read_bytes()
    client.publish(AUDIO_TOPIC, audio_bytes, qos=1)
    print(f"Published audio through MQTT: {AUDIO_FILE} ({len(audio_bytes)} bytes)")
    return True


def ensure_log_file():
    """
    Create a compatible CSV log.

    If an older log has a different header, preserve it with a timestamped name.
    """
    LOG_DIR.mkdir(exist_ok=True)

    if LOG_FILE.exists():
        try:
            with LOG_FILE.open("r", newline="", encoding="utf-8") as file:
                existing_header = next(csv.reader(file), [])
        except (OSError, StopIteration):
            existing_header = []

        if existing_header == LOG_FIELDNAMES:
            return

        timestamp = datetime.now().strftime("%Y%m%d_%H%M%S")
        archived_file = LOG_DIR / f"broadcast_log_before_llm_{timestamp}.csv"
        LOG_FILE.rename(archived_file)
        print(f"Archived old log file: {archived_file}")

    with LOG_FILE.open("w", newline="", encoding="utf-8") as file:
        writer = csv.DictWriter(file, fieldnames=LOG_FIELDNAMES)
        writer.writeheader()

    print(f"Created log file: {LOG_FILE}")
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

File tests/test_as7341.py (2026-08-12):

import time
import board
from adafruit_as7341 import AS7341

# Use Raspberry Pi default I2C pins: SDA=GPIO2, SCL=GPIO3
i2c = board.I2C()

# Create AS7341 sensor object
sensor = AS7341(i2c)

print("AS7341 detected. Reading spectral channels...")
print("Cover the sensor, shine a phone torch, or point it at different lights to test changes.\n")

while True:
    # Read visible spectrum channels and clear/NIR channels
    ch_415 = sensor.channel_415nm
    ch_445 = sensor.channel_445nm
    ch_480 = sensor.channel_480nm
    ch_515 = sensor.channel_515nm
    ch_555 = sensor.channel_555nm
    ch_590 = sensor.channel_590nm
    ch_630 = sensor.channel_630nm
    ch_680 = sensor.channel_680nm
    clear = sensor.channel_clear
    nir = sensor.channel_nir

    # Simple derived values for quick interpretation
    blue_part = ch_445 + ch_480
    green_part = ch_515 + ch_555
    red_part = ch_630 + ch_680

    print("------ AS7341 Reading ------")
    print(f"415nm violet: {ch_415}")
    print(f"445nm blue  : {ch_445}")
    print(f"480nm cyan  : {ch_480}")
    print(f"515nm green : {ch_515}")
    print(f"555nm green : {ch_555}")
    print(f"590nm yellow: {ch_590}")
    print(f"630nm red   : {ch_630}")
    print(f"680nm red   : {ch_680}")
    print(f"Clear       : {clear}")
    print(f"NIR         : {nir}")
    print(f"Blue sum    : {blue_part}")
    print(f"Green sum   : {green_part}")
    print(f"Red sum     : {red_part}")
    print()

    time.sleep(1)

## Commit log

2026-05-25 Initial working prototype with sensors, Azure TTS and MQTT audio
2026-05-27 Add Raspberry Pi local audio playback
2026-08-12 Add final hardware bill of materials
2026-08-12 Add 3D models
    [Body2.stl, base.stl, bottom.stl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]
